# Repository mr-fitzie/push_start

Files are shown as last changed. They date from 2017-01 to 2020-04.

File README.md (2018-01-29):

# push_start
Simple push button start system for an automobile utilzing an Ardunio microcontroller and a few relays.

## Circuit Design
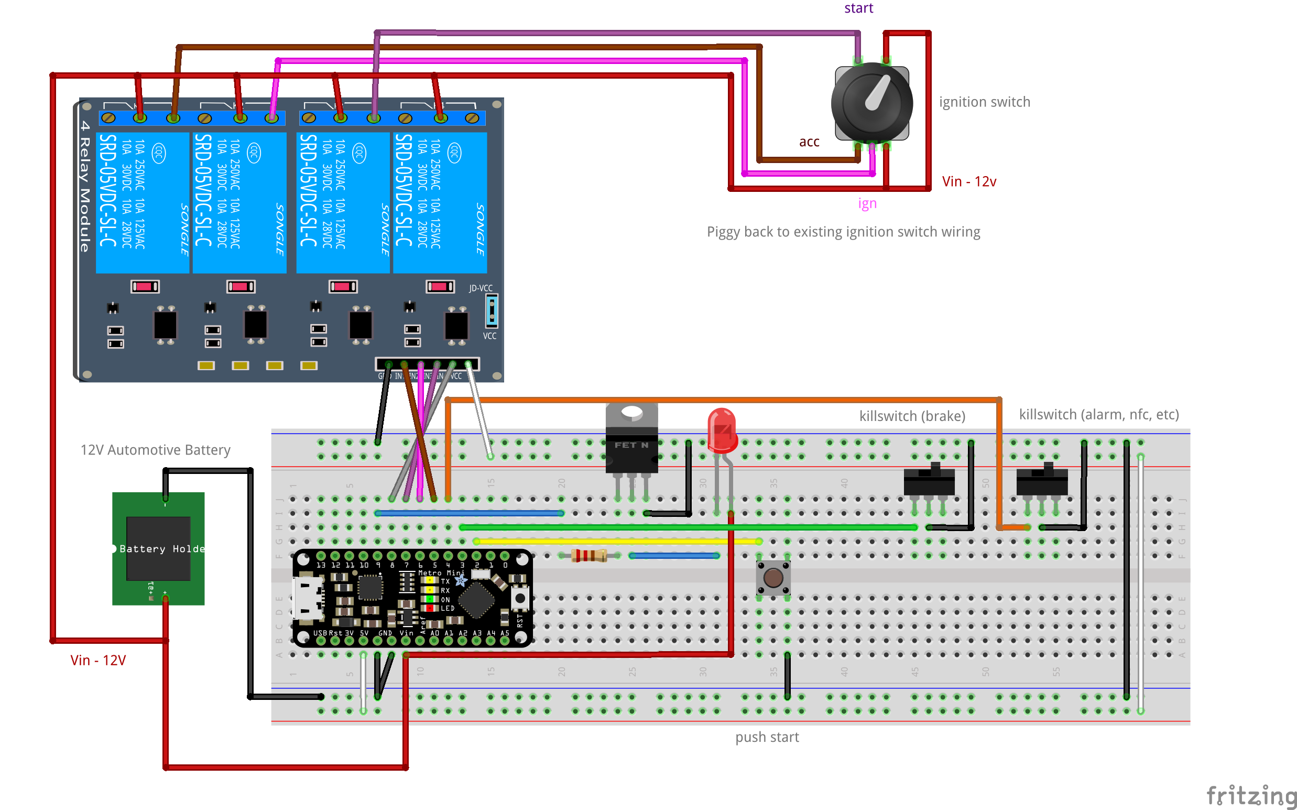
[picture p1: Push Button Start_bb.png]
circuit


## License
```
MIT License

Copyright (c) 2016 Chris Fitzpatrick

Permission is hereby granted, free of charge, to any person obtaining a copy
of this software and associated documentation files (the "Software"), to deal
in the Software without restriction, including without limitation the rights
to use, copy, modify, merge, publish, distribute, sublicense, and/or sell
copies of the Software, and to permit persons to whom the Software is
furnished to do so, subject to the following conditions:

The above copyright notice and this permission notice shall be included in all
copies or substantial portions of the Software.

THE SOFTWARE IS PROVIDED "AS IS", WITHOUT WARRANTY OF ANY KIND, EXPRESS OR
IMPLIED, INCLUDING BUT NOT LIMITED TO THE WARRANTIES OF MERCHANTABILITY,
FITNESS FOR A PARTICULAR PURPOSE AND NONINFRINGEMENT. IN NO EVENT SHALL THE
AUTHORS OR COPYRIGHT HOLDERS BE LIABLE FOR ANY CLAIM, DAMAGES OR OTHER
LIABILITY, WHETHER IN AN ACTION OF CONTRACT, TORT OR OTHERWISE, ARISING FROM,
OUT OF OR IN CONNECTION WITH THE SOFTWARE OR THE USE OR OTHER DEALINGS IN THE
SOFTWARE.
```

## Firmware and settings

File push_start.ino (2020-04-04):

/**
 * Push Button Start 
 * 
 * Simple circuit that implements a push button start system for an automobile
 * The system has 4 distinct states
 * * DISABLED - Vehicle is powered off and cannot be turned on
 * * OFF - Vehicle is powered off
 * * ACC - Vehicle is in accessory mode
 * * START - Vehicle is starting
 * * RUN - Vehicle is running
 * 
 * The system uses 4 relays or FETs to drive the existing vehicle start circuits
 * When the system is:
 * * DISABLED the relays are deenergized/OFF and cannot be enabled
 * * OFF all relays are deenergized/OFF
 * * ACC the RELAY_ACC is energized/ON
 * * START the RELAY_START and RELAY_IGN are energized/ON
 * * RUN the RELAY_IGN is energized/ON
 * 
 * If the KILL_SWITCH circuit is grounded then the whole system is DISABLED and the relays are
 * immediately deenergized and the button no longer can transition states. If the circuit is
 * opened the system transitons to the OFF state.
 * 
 * When the kill switch is closed the system is enabeled and has the basic flow of:
 * OFF -> ACC -> (OFF | START) -> RUN -> (OFF | ACC)
 * * To transition from OFF -> ACC depress and release the push button
 * * To transition from ACC -> OFF depress and release the push button under HOLD_MS (1sec)
 * * To transition from ACC -> (START) -> RUN depress and hold the push button in until 
 * * vehicle is started and then release the button. The initial depress starts a timer that
 * * once held for over HOLD_MS (1sec) puts the system in START mode and then the release
 * * of the button once the vehicle is started transitions to RUN mode. Note, if the 
 * * SAFE_SWITCH is grounded the this transition will not be conducted.
 * * To transition from RUN -> OFF depress and release the push button.
 * * To transition from RUN -> ACC depress and hold the push button longer than HOLD_MS 
 * * (1sec) then release.
 * 
 * Because the timing to kick over the motor can be different for various vehicles and you
 * do not want not run the starter too long which may grind the flywheel/flexplate teeth the
 * I decided to keep the amount of time the starter is engaged to the actual press, just like
 * turning a key. The system could be modified to do it based on time in the future.
 * 
 * NFC
 * Can be used as a substitute for a wired KILL_SWITCH. The code below uses the PN532 library
 * from Elechouse (https://github.com/elechouse/PN532). To enable the starting system the system
 * will check the UID of the item close to the NFC antenna and make sure its in the approved 
 * list defined in the NFC_UIDS array. As long as the token is by the antenna the system will
 * stay active, if the token is removed from the antenna as soon as the system transitions to OFF
 * the token will be required to reenable the system. To get the UID of your tokens use the
 * PN532 readMifare example or the commented out debugging code that outputs the tokens UID.
 * 
 * 
 * @author Chris Fitzpatrick
 * @version 2.0 03/24/2020
 * @license MIT License
 */

// Defines
#define RELAY_ON        HIGH    // Relay Energized State (HIGH or LOW)
#define RELAY_OFF       LOW     // Relay Deenegized State (Opposite of RELAY_ON)

#define PUSH_BTN_PRESS  HIGH    // Push Button Pressed State (HIGH or LOW)

#define SAFE_SWITCH_ENB HIGH    // Safety Switch enabled

#define NFC_KILL_SWITCH 1       // 1=Enable NFC Kill Switch, 0=Enable Physical KILL_SWITCH

#if NFC_KILL_SWITCH
  // Use the PN532 Module in I2C mode, see PN532 examples for using in HSU or SPI modes
  #include <Wire.h>
  #include <PN532_I2C.h>
  #include <PN532.h>
  PN532_I2C pn532i2c(Wire);
  PN532 nfc(pn532i2c);

  byte NFC_UIDS[][7] = {
       {0x69, 0xAF, 0xEC, 0xC2, 0x00, 0x00}, // Fob
       {0x79, 0x5A, 0x13, 0xB1, 0x00, 0x00}  // Card
  };
#endif

// Pin Definitions

// LEDs
const int LED_BUTTON   = 9;  // Push button LED
const int LED_ON_BOARD = 13; // Onboard may not fade if there is no PWM attached,
                             // but can at least give indication of state when not  
                             // using 12v input for testing/debug
// Switches
const int PUSH_BUTTON = 6;   // Momentary push button
const int KILL_SWITCH = 3;   // This is any input to enable/disable the system, could be NFC 
                             // trigger/physical switch, if grounded system is disabled.
const int SAFE_SWITCH = 5;   // Brake/Clutch/Neutral safety switch, if grounded cannot start.
                             
// Relays
const int RELAY_ACC   = 18;
const int RELAY_IGN   = 21;
const int RELAY_START = 19;  
const int RELAY_4     = 8;   // Not Used

// Speaker
const int SPEAKER     = 22;

// System state
enum sysState {
  DISABLED,
  OFF,
  ACC,
  START,
  RUN
};

// Globals
const int FLASH_DELAY = 10;     // How many ticks to pass through before turning on/off LED
                                // when in ACC state. Increasing this number makes the blink
                                // slower. Since the main loop sleeps 30ms a value of 10 here
                                // waits 300ms in ON then 300ms in OFF.
                                                          
const int HOLD_MS = 1000;       // Milliseconds to hold button to transition from ACC->START 
                                // or from RUN->ACC                             
                 
unsigned int tick = 0;          // Count cycles for LED flash mode (unsigned so when it rolls
                                // over it restarts at 0
int brightness = 0;             // How bright the LED is (usable range 0-255)
int fadeAmount = 5;             // How many points to fade the LED by when in OFF state  

int previousButtonState = !PUSH_BTN_PRESS;  // Stores the previous button state so we can see if it changes
long pressTime;                 // When the button was pressed 

sysState runState = DISABLED;   // Stores current system run state

/**
 * Setup runs once when system is reset, Setup pins and default states
 */
void setup() {
  // Initialize serial communication at 9600 bits per second
  Serial.begin(9600);
  // Leonardo/Micro delay, only uncomment for debugging will prevent running without Serial
  //while(!Serial) { delay(10); }

#if NFC_KILL_SWITCH
  // Setup NFC
  nfc.begin();
  unsigned long versiondata = nfc.getFirmwareVersion();
  if (! versiondata) {
    Serial.print("Didn't find PN53x board");
    while (1); // halt
  }
  // Got ok data, print it out!
  Serial.print("Found chip PN5"); Serial.println((versiondata>>24) & 0xFF, HEX); 
  Serial.print("Firmware ver. "); Serial.print((versiondata>>16) & 0xFF, DEC); 
  Serial.print('.'); Serial.println((versiondata>>8) & 0xFF, DEC);
  
  // configure board to read RFID tags
  nfc.SAMConfig();
#endif

  // Setup Pins
  pinMode(LED_BUTTON, OUTPUT);
  pinMode(LED_ON_BOARD, OUTPUT);
  
  pinMode(PUSH_BUTTON, INPUT);
  pinMode(KILL_SWITCH, INPUT_PULLUP);
  pinMode(SAFE_SWITCH, INPUT_PULLUP); 
  
  pinMode(RELAY_ACC, OUTPUT);
  pinMode(RELAY_IGN, OUTPUT);
  pinMode(RELAY_START, OUTPUT);

  pinMode(SPEAKER, OUTPUT);
  
  // Disable relays at start
  // RELAY_OFF == Denergized, RELAY_ON = Energized
  digitalWrite(RELAY_ACC, RELAY_OFF);
  digitalWrite(RELAY_IGN, RELAY_OFF);
  digitalWrite(RELAY_START, RELAY_OFF);

  Serial.println("+------ Push Button Start System v2.0 ------+");
  Serial.println("| MIT License                               |");
  Serial.println("| Copyright (c) 2016-2020 Chris Fitzpatrick |");
  Serial.println("| https://github.com/mr-fitzie/push_start   |");
  Serial.println("+-------------------------------------------+");
  printState(runState);
  playDisabledChime();
}

/**
 * Main Run Loop
 */
void loop() {
  // Set the brightness of LEDs:
  analogWrite(LED_BUTTON, brightness);
  analogWrite(LED_ON_BOARD, brightness);
  
  // System is enabled, process as normal
  if (systemEnabled()) { 
    // If we were disabled move to OFF
    if (runState == DISABLED) {
      runState = OFF;
      printState(runState);
      playEnabledChime(); 
    }
    
    // Read in the button state to see if it has been pressed
    int buttonState = digitalRead(PUSH_BUTTON);
    if (buttonState != previousButtonState) {
      // Transition on released state for most states
      if (buttonState != PUSH_BTN_PRESS) { // Released
        Serial.println("Released");
        switch (runState){
          case DISABLED: // Disabled -> Off
            // This state should never be hit, but is included for completeness.
            runState = OFF;
            break;
          case OFF: // Off -> Acc
            runState = ACC;
            break;
          case ACC: // Acc -> Off (Acc -> Start handled below)
            runState = OFF;
            break;
          case START: // Start -> Run
            runState = RUN;
            break;
          case RUN: // Run -> Off or ACC          
            // Transition back to ACC if button was held longer than HOLD_MS otherwise
            // go to OFF.
            runState = OFF;
            if (millis() - pressTime > HOLD_MS) {
              // In order for the engine to turn off to we need to transition to OFF, 
              //wait and then to ACC  
              setRelayState();
              delay(500);
              runState = ACC;
            }
            break;
        }
        printState(runState);
        setRelayState();
      } else { // Pressed
        pressTime = millis();
        Serial.println("Pressed");
      } 
    } else if (buttonState == PUSH_BTN_PRESS) { // Pressed
      // Special case for START
      // When we release the push button in the ACC state we want to transition to
      // START if held longer than HOLD_MS and the SAFE_SWITCH is open
      if (runState == ACC) {
        bool safe = digitalRead(SAFE_SWITCH) != SAFE_SWITCH_ENB; // ENB = Unsafe to start
        if (safe) {
          if(millis() - pressTime > HOLD_MS) {
            runState = START;
            printState(runState);
            setRelayState();
          }
        } else {
          Serial.println("WARNING: Unsafe to Start");
        }
      }
    }
    // Store button state for next cycle
    previousButtonState = buttonState;
  } else {
    if (runState != DISABLED) {
      printState(DISABLED);
      playDisabledChime();
    }
    runState = DISABLED;
    setRelayState();
  }
  // Set brightness for next cycle
  setLedBrigtness();
  // Wait for 30 milliseconds
  delay(30);
}

/**
 * Sets the relays depending on the current system run state
 * 
 * DISABLED - All Off
 * OFF      - All Off
 * ACC      - ACC On
 * START    - ACC On IGN On
 * RUN      - IGN On
 * 
 * @return none
 */
void setRelayState() {
  switch (runState){
    case DISABLED: 
    case OFF:
      digitalWrite(RELAY_ACC, RELAY_OFF);
      digitalWrite(RELAY_IGN, RELAY_OFF);
      digitalWrite(RELAY_START, RELAY_OFF);
      break;
    case ACC:
      digitalWrite(RELAY_ACC, RELAY_ON);
      digitalWrite(RELAY_IGN, RELAY_OFF);
      digitalWrite(RELAY_START, RELAY_OFF);
      break;
    case START:
      digitalWrite(RELAY_ACC, RELAY_OFF);
      digitalWrite(RELAY_IGN, RELAY_ON);
      digitalWrite(RELAY_START, RELAY_ON);
      break;
    case RUN:
      digitalWrite(RELAY_ACC, RELAY_OFF);
      digitalWrite(RELAY_IGN, RELAY_ON);
      digitalWrite(RELAY_START, RELAY_OFF);
      break;
  }
}

/**
 * Sets the LED brightness depending on the current system run state
 * 
 * DISABLED - Off
 * OFF      - Fade In/Out
 * ACC      - Flashing
 * START    - Rapid Flashing
 * RUN      - On Solid
 * 
 * @return none
 */
void setLedBrigtness() {
  switch (runState) {
    case DISABLED: // Solid Off
      brightness = 0;
      break;
    case OFF: // Fade / Breath
      // Change the brightness for next time through the loop
      brightness = brightness + fadeAmount;

      // The following two checks will eliminate a quick flash if we
      // enter this loop from one of the other states with a number
      // above or below the max.
      if (brightness + fadeAmount > 255) {
        brightness = 255;
      }
      else if (brightness + fadeAmount < 0) {
        brightness = 0;
      }
      
      // Reverse the direction of the fading at the ends of the fade
      if (brightness <= 0 || brightness >= 255) {
        fadeAmount = -fadeAmount;
      }
      break;
     case ACC: // Flashing
      // For every <FLASH_DELAY> ticks turn the LED on or off
      if (tick % FLASH_DELAY == 0) {
        if (brightness > 0) {
          brightness = 0;
        } else {
          brightness = 255;
        }
      }
      tick++;
      break;
     case START: // Rapid Flashing
      if (brightness > 0) {
        brightness = 0;
      } else {
        brightness = 255;
      }
      break;
     case RUN: // Solid On
      brightness = 255;
      break;
  }
}

/**
 * Prints the current system state
 * 
 * @param  state Current system state
 * @return none
 */
void printState(sysState state) {
  String strState;
  switch (state) {
     case DISABLED:  
        strState = "DISABLED";
        break;
     case OFF:
        strState = "OFF";
        break;
     case ACC:
        strState = "ACCESSORY";
        break;
     case START:
        strState = "STARTING";
        break;
     case RUN:
        strState = "RUNNING";
        break;
  }
  Serial.println("System State: " + strState);
}

/**
 * Play Disabled Chime
 * 
 * @return none
 */
void playDisabledChime() {
  tone(SPEAKER, 2000, 250);
  delay(250);
  tone(SPEAKER, 4000, 250);
}

/**
 * Play Enabled Chime
 * 
 * @return none
 */
void playEnabledChime() {
  tone(SPEAKER, 4000, 250);
  delay(250);
  tone(SPEAKER, 2000, 250);  
}

/**
 * Checks to see if the system is enabled which will allow the vehicle 
 * to be started
 * 
 * @return bool true if system is enabled, false if disabled
 */
bool systemEnabled() {
#if NFC_KILL_SWITCH
  bool enabled = false;  
  bool success = false;
  byte uid[] = { 0, 0, 0, 0, 0, 0, 0 };  // Buffer to store the returned UID
  byte uidLength;                        // Length of the UID (4 or 7 bytes depending on ISO14443A card type)

  // If the system has already been enabled from NFC and started keep it enabled
  // until the car is turned OFF
  if (runState != DISABLED && runState != OFF) {
    return true;
  }

  success = nfc.readPassiveTargetID(PN532_MIFARE_ISO14443A, uid, &uidLength, 25);  
  //Serial.print("UID Value: ");
  //nfc.PrintHex(uid, uidLength);
  //Serial.println("");
  bool found = false;
  for (byte i = 0; i < (sizeof(NFC_UIDS) / sizeof(NFC_UIDS[0])); i++) {
    //Serial.print("Compare to known UID: ");
    //nfc.PrintHex(NFC_UIDS[i], sizeof(NFC_UIDS[i]));
    if (checkUid(NFC_UIDS[i], uid, sizeof(NFC_UIDS[i]))) {
      //Serial.println("UID Match");
      found = true;
      break;
    }
  }
  return found;
#else
  return digitalRead(KILL_SWITCH) == HIGH; // HIGH = System Enabled LOW = Disabled (grounded)
#endif
}

/**
 * Compares known UID to UID to see if they match
 * 
 * @return bool true if UID is a match, false if not
 */
bool checkUid(byte knownUid[], byte uid[], byte uidLength) {
  for (byte i = 0; i < uidLength; i++) {
    if (knownUid[i] != uid[i]) {
      return false;
    }
  }
  return true;
}

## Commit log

2016-12-30 Simple Push Button Start
    [Push Button Start.fzz]
2017-01-03 Updated Circuit - Works in Vehicle
    Updated Fritzing to reflect relay out puts (using rotary encoder as mock
    ign switch) and secondary kill switch input. Fixed code to go from
    DISENGAGED to OFF state. Code does not yet utilize 2nd kill switch.
    System was tested in vehicle successfully.
    [Push Button Start.fzz]
2017-01-03 Fix Wire Locations on Fritzing
    Fixed Relay K-ON and Killswitch COM wiring
    [Push Button Start.fzz]
2017-02-12 New Transition States, SAFE_SWITCH, Serial Output
    Added ACC->OFF (press button for less than 1sec) and RUN->ACC (press and
    hold for more than 1sec before release) transitions. Toggled state
    changes to button release with the exception of ACC->START (press and
    hold for more than 1sec). SAFE_SWITCH must be open for ACC->START.
    Extracted relay setting to setRelayState() and added printState(state)
    to print the system state to the console.
